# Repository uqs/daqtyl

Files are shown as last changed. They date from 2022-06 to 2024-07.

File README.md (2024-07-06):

# Ftraqtyl Keyboard

The Ftraqtyl is a family member of the Dactyl-Manuform family of keyboards with
added trackball support for finger-operated trackballs.

The genealogy goes roughly like this, with no claim to be accurate:

- [Dactyl](https://github.com/adereth/dactyl-keyboard): Clojure!
- [ManuForm](https://github.com/jeffgran/ManuForm): thumb cluster
- [Dactyl-ManuForm](https://github.com/tshort/dactyl-keyboard): combination
- [Dactyl-Manuform Mini](https://github.com/l4u/dactyl-manuform-mini-keyboard): Mini thumb cluster
- [carbonfet](https://github.com/carbonfet/dactyl-manuform): new cluster
- [crystalhand](https://github.com/crystalhand/dactyl-keyboard): palm rests
- /u/qqurn, /u/drashna, [/u/noahjoseph](https://github.com/noahprince22/tractyl-manuform-keyboard): trackball mad lads.

## Other variants you should check out

- https://github.com/okke-formsma/dactyl-manuform-tight/
- https://github.com/geoffder/dometyl-keyboard

Shoutout also to the folks from OhKeycaps who inadvertently got me started on this journey.

## Notable Changes

- Trackball holder for the fingers (!) of the right hand.
- Trackballs don't use dowels or ball bearings, but press-fit steel balls. I prefer the feel of this, but might try BTUs also.
- Tighter vertical spacing, works for MT3 keycaps.
- Tighter horizontal spacing for first and last column. First column also slanted inwards. Last column splayed a bit.
- Three button cluster based off the "mini" cluster.
- Palm rests without silicone pads.
- Rolling rotary encoders (like a proper mouse wheel).
- Support for 34mm and 44mm trackballs.

## Generate OpenSCAD and STL models

This requires the unreleased (yet) version of scad-clj, you should be able to clone scad-clj and run `lein jar && lein install`.
(This will be obsolete once https://github.com/farrellm/scad-clj/issues/49 has been resolved).

To create everything, just run `lein generate && make -j4 all`, otherwise:

* Run `lein repl`, enter: `(load-file "src/dactyl_keyboard/dactyl.clj")`
* This will regenerate the `things/*.scad` files
* Use OpenSCAD to open a `.scad` file.
* Make changes to design, repeat `load-file`, OpenSCAD will watch for changes and rerender.
* When done, use OpenSCAD to render and export STL files, either from UI or using `openscad --export-format binstl -o right.stl things/right.scad`

## License

Copyright © 2015-2024 Matthew Adereth, Tom Short, Leo Lou, carbonfet, crystalhands, and Ulrich Spörlein.

The source code for generating the models is distributed under the [GNU AFFERO GENERAL PUBLIC LICENSE Version 3](LICENSE).

The generated models are distributed under the [Creative Commons Attribution-ShareAlike 4.0 International (CC BY-SA 4.0)](LICENSE-models).

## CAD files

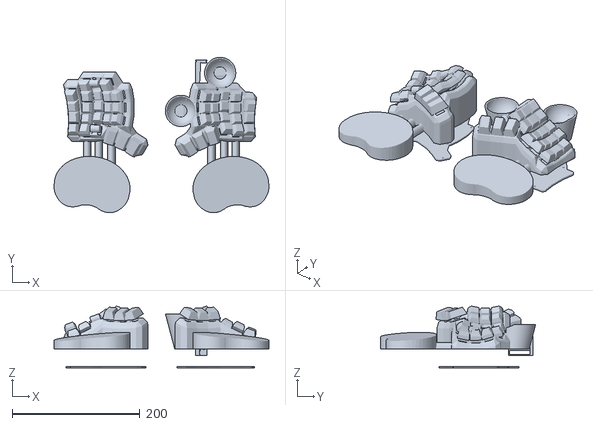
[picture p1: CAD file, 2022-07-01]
things/all-test.dec.stl
337.1 x 243.6 x 97.2

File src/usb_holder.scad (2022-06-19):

/* there's tons of magic numbers here because 
 * i exported a semi-done parametric version from clojure
 * and didn't fix all the formulas for x and y translates....
 * before getting it fully working and for getting how the working scad version
 * diverged from the clojure version.......................
 *
 * sorry future person trying to change this, you will need 
 * a strong dragon spear to modify any 'kinda adjustable' values */

reset_holder = true;
vertical = true;
cutout_blank = false;
show_previous = false;

controller_adj = 0.0;

usb_holder_x = 30.6;       // kinda adjustable
usb_holder_y = 38.8 + controller_adj;       // kinda adjustable
usb_holder_z = reset_holder? 15 : 8.4;        // kinda adjustable

usb_holder_border = 1.5;   // kinda adjustable

/* this combination of controller and usb_c dimensions 
 * friction fits both generations of elite-c controllers */
usb_elite_c_x = 18.7;      // kinda adjustable
usb_elite_c_y = 33.4 + controller_adj;      // mostly adjustable
usb_elite_c_side_cut = 6;  // adjustable

usb_c_x = 9.3;             // adjustable
usb_c_z = 4.0;             // kinda adjustable

trrs_x = 6.2;              // mostly adjustable
trrs_y = 12.7;             // kinda adjustable
trrs_r = 3.25;             // adjustable

usb_holder_center_x = usb_holder_x / 2;
usb_holder_center_y = usb_holder_y / 2;
usb_holder_center_z = usb_holder_z / 2;

usb_holder_notch_xy = usb_holder_border;
usb_holder_notch_down = usb_holder_border * usb_holder_notch_xy;
usb_holder_notch_half = usb_holder_notch_xy / 2;

$fn = 100;

module basicShape() {
  difference () {
    //basic starting shape to cut away from  `
    cube ([usb_holder_x, usb_holder_y, usb_holder_z], center=true);
    
    left_cut_x = 2 * usb_holder_border;
    left_cut_y = 3 * usb_holder_border;
    
    bottom_cut_x = (left_cut_x + trrs_x);
    bottom_cut_y = (left_cut_x + trrs_x);
    
    cut1_x = (usb_holder_center_x -  usb_holder_border);
    cut1_y = (usb_holder_center_y - (usb_holder_center_y - left_cut_y/2));
    
    cut2_x = (usb_holder_center_x - (bottom_cut_x / 2));
    //cut2_y = (usb_holder_center_y - (- usb_holder_center_y (16.6 / 2))); //todo
      
    //misc magic numbers
    if (!cutout_blank) {
      union () {
        translate ([-cut1_x, -cut1_y, 0]) {
          cube ([left_cut_x, (usb_holder_y - left_cut_y), 99], center=true);
        }
        translate ([-cut2_x, -8.3, 0]) {
          cube ([bottom_cut_x, (usb_holder_y - 16.6), 99], center=true);
        }
        rotate (a=3, v=[1, 0, 0]) {
          top_cut_adjust = reset_holder? 1.75*usb_holder_border : usb_holder_border;
          translate ([0, -(usb_holder_border * 3), (usb_holder_z / top_cut_adjust) ]) {
            cube ([usb_holder_x, usb_holder_y, usb_holder_z], center=true);
          }
        }
      }
    }
    
    if (!vertical) {
      // side notches that key into other object
      notch_x = (usb_holder_center_x - usb_holder_notch_half);
      notch_y = (usb_holder_center_y - usb_holder_notch_down);
      translate ([ notch_x, notch_y, 0]) { notch(); }
      translate ([-notch_x, notch_y, 0]) { notch(); }
    }
  }
}
module notch() {
    cube ([usb_holder_notch_xy, usb_holder_notch_xy - 0.05, 30.6], center=true);
}

module trrsCutouts() {
    trrs_floor = 1;
    trrs_squareCutoutHeight = 12;
    trrs_squareCutoutHeightOffset = trrs_floor - usb_holder_center_z + trrs_squareCutoutHeight/2;
    translate ([-9.2, 11.65 + controller_adj/2, trrs_squareCutoutHeightOffset]) {
        cube ([trrs_x, trrs_y, trrs_squareCutoutHeight], center=true);
    }
    
    trrsAngle_z_adjust = reset_holder? 0.5 : 4;
    trrsAngle_z_factor = reset_holder? 0.5 : 1;
    translate ([-9.2, 11.65-trrs_y/3+ controller_adj/2, trrsAngle_z_adjust * usb_holder_border]) {
        rotate (a=-72.0, v=[1, 0, 0]) {
            cube ([trrs_x, trrs_y, usb_holder_z * trrsAngle_z_factor], center=true);
        }
    }
    
    trrs_y_offset = (usb_holder_center_y - (usb_holder_border / 2) +0.01);// + controller_adj;
    trrs_z_offset = (usb_holder_center_z - (trrs_floor + trrs_r));
    translate ([-9.1, trrs_y_offset, -trrs_z_offset]) {
        rotate (a=90.0, v=[1, 0, 0]) {
           cylinder (h=(usb_holder_border * 2), r=trrs_r, center=true);
        }
    }
}

module resetCutout() {
    reset_xz = 7.1;
    reset_y = 4.4;
    reset_floor = usb_holder_z / 1.5 ;
    reset_r = 1.90;
    
    reset_x_offset = usb_holder_center_x - usb_elite_c_x / 2 - usb_holder_border;
    reset_y_offset = usb_holder_center_y - usb_elite_c_y - usb_holder_border;
    reset_z_offset = usb_holder_center_z - (reset_floor + reset_r);
    
    translate ([reset_x_offset, -reset_y_offset, -reset_z_offset]) {
        cube ([reset_xz, reset_y, reset_xz], center=true);
    }
    
    translate ([reset_x_offset, 0, -reset_z_offset]) {
        rotate (a=90.0, v=[1, 0, 0]) {
          cylinder (h=99, r=reset_r, center=true);
        }
    }
}

module eliteC() {
    x_offset = ( (usb_holder_center_x - (usb_elite_c_x / 2)) - usb_holder_border);
    y_offset = (-(usb_holder_center_y - (usb_elite_c_y / 2)) + usb_holder_border);
    z_offset = usb_holder_border;
    translate ([x_offset, y_offset, z_offset]) {
        cube ([usb_elite_c_x, usb_elite_c_y, usb_holder_z], center=true);
    }

    left_cut_x  = ((usb_holder_center_x - (usb_elite_c_x / 2)) - ((usb_elite_c_x / 2) - (usb_elite_c_side_cut / 2)) - usb_holder_border);
    right_cut_x = ((usb_holder_center_x - (usb_elite_c_x / 2)) + ((usb_elite_c_x / 2) - (usb_elite_c_side_cut / 2)) - usb_holder_border);
    translate ([left_cut_x , y_offset, 0]) { circuitBoardSlots(); }
    translate ([right_cut_x, y_offset, 0]) { circuitBoardSlots(); }

    usbPort_z_adjust = reset_holder? -3.6 : -0.3;
    translate([0, 0, usbPort_z_adjust]) {
        usbPortCutout();
        usbRecessCutout();
    }
}

module circuitBoardSlots() {
    cube ([usb_elite_c_side_cut, usb_elite_c_y, 99], center=true);
}

module usbPortCutout() {
    usbPortCenter = ((usb_holder_center_x - (usb_elite_c_x/2)) - usb_holder_border);
    usbPortCenterCut = (usb_c_x - usb_c_z);
    usbPortSideOffset = usbPortCenterCut / 2 + 0.15;
    usbPortCenterCutLength = 20;
    
    translate ([usbPortCenter, 20, 0]) {
      hull() {
	rotate (a=90.0, v=[1, 0, 0]) {
	  translate ([-usbPortSideOffset, 0, 0]) {
	    cylinder (h=usbPortCenterCutLength, r=usb_c_z/2);
	  }
	  translate ([usbPortSideOffset, 0, 0]) {
	    cylinder (h=usbPortCenterCutLength, r=usb_c_z/2);
	  }
	}
      }
    }
}

module usbRecessCutout() {
    usb_c_cover_plate = usb_holder_border;
    recess_y = (usb_holder_y - usb_elite_c_y - usb_holder_border - usb_c_cover_plate);
    recess_z = 8;
    translate ([0, (usb_holder_center_y - (recess_y / 2) +0.01), 0]) {
        
        translate ([0, 0, 0]) {
            rotate (a=90.0, v=[1, 0, 0]) {
                cylinder (h=recess_y, r=3.25, center=true);
            }
        }
        translate ([(+(usb_holder_center_x - (usb_elite_c_x/2)) - usb_holder_border), 0, 0]) {
            cube ([12.5, recess_y, recess_z], center=true);
        }
        translate ([(usb_c_x), 0, 0]) {
            rotate (a=90.0, v=[1, 0, 0]) {
                cylinder (h=recess_y, r=3.25, center=true);
            }
        }
    }
}

// main method
module usb_holder() {
    //adjust origin to front fact, bottom, mostly to match existing STLs
    translate([0, -(usb_holder_y/2), (usb_holder_z/2)]) {
        
        difference () {
            basicShape();
            if (!cutout_blank) {
                trrsCutouts();
                eliteC();
                if (reset_holder) {
                    resetCutout();
                }
            }
        }
    }
    if (show_previous) {
        color( "grey", 0.6 )
          translate([0,0,0])
            union() {
              rotate([0,0,0])
              import("../elite-c_holder_w_reset.stl");
            }
    }
}
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

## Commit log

2020-05-03 Fix keycaps and add plate generation
2020-06-25 Add files via upload
    Slightly tweaked the shape of the TRRS holder & loosened the tolerance on the TRRS hole.
    [controller holder (elite-c).stl, controller holder.stl]
2020-07-27 Update dactyl.clj
    Minor tweak to thumb cluster, tweak screw post to remove domed top (shortening it).
2020-11-12 Update dactyl.clj
    Fixed keycap colliding with case by widening switch plate slightly, other minor tweaks.
2020-11-13 Update dactyl.clj
    Increased thickness of the 'switchplate' to 4.5mm. Increased thickness of the web connectors to 4.5mm as well to smooth out the bottom of the switchplate.
2020-11-16 Update dactyl.clj
    Fixing a gap in the connectors when extra-row was set to false.
2020-12-06 Update dactyl.clj
    Screw posts now behave better when switching between different layout styles.
2021-03-03 Add files via upload
    Updated to shorter holders, elite-c holder should now be compatible with elite-c v4.
    [elite-c holder.STL, pro micro holder.STL]
2021-04-11 Update dactyl.clj
    Minor bugfix for bottom plate generation; should behave better with certain combinations now.
2021-04-25 Update dactyl.clj
    Added a 6th screw post near the middle of the back wall
2021-06-18 Update dactyl.clj
    Added more lines for top-middle screw post definition.
2021-08-28 Let's try this one, first build with a mini cluster
    Use more tenting and fix the screw inset offsets that are
    then off.
    TODO: add the holes for the wrist rest attachment
2021-08-29 Bring over the wrist rest with connectors from crystalhand
2021-09-12 name files a bit better, drop laser plate, add bottom plate to test
2021-09-12 cut off the bottom of the wirst rest cylinders properly
2021-09-20 Make the wrist-rest a bit hollow and thus cheaper to print
2021-09-25 Remove thumb connectors to the extra row (what???) that don't change the output at all.
2021-09-27 Change from MX switch holder to some half-assed structure to hold the rotary encoder
2021-09-27 Fold pinky-connectors and keyhole-inner inline. Duplicate the left model, as we need to parametrize it shortly.
2021-09-27 Provide my own version of the 3 button cluster, which is simply the mini cluster with 2 keys removed.
    Need to check clearing for 1.5u keys still.
2021-10-09 Make the bottom plate a recessed plate and move the screw inserts up.
    This conflicts with a lot of things and the whole case needs to be
    elevated a bit.
    I'm not happy with the uneven width of the walls anyway ...
2021-10-31 Place new, custom trackball holder for a test print.
2021-10-31 Fix the missing screw recess for the bottom plate.
    It still is not right and won't fit into the top ...
2021-10-31 Fix thumb cluster oddity and remove the need to cut off the bottom
    Increase height a little so we have space for the plate and screw
    inserts. This will need to be scaled down a little again.
2021-10-31 Order screw posts
2021-11-01 Try with the encoder place in the last row as well.
2021-11-01 Move screw inserts around some more and fix them in the OpenSCAD preview.
2021-11-02 Add the encoder cylinder to the preview and fix trackball z translation.
    Turn on all STL exports for publishing v1 as well.
2021-11-03 Shear the trackball holder a bit towards the case.
2021-11-04 Fix some more thumb cluster nits and the palm rest connectors and cutouts
2021-11-11 Fix screw insets to be more like crystalhand's
2021-11-11 Fix two holes in the model, sheesh.
2021-11-13 Lower keeb by 6mm, enlarge the screw-inserts and shrink the bottom plate a little.
2021-11-13 Add sensor holder and cutout
    This is no good though, sliding the sensor in from the top obviously
    won't work. Sigh ...
2021-11-21 Encoder only on the left side, on the right it inteferes with my numpad layer.
2021-11-21 Switch to 4x5! Hurray for combos!
2021-11-22 Slim down the encoder plate, but also raise it higher.
2021-11-27 Tweaks to the encoder plate to improve fit and access to pins.
2021-11-28 Tweak the connectors around the encoder plate to allow easier access from the bottom for soldering them.
2021-11-29 Convert more stuff to STL for inspection in FreeCAD
2021-11-29 Fix the projection for the bottom plate by pluggin encoder holes.
2021-11-29 Break down walls between keyboard and trackball, noting that the sensors will not fit with the current design.
    Also make all models compile again.
2021-11-30 Remove STLs w/o sources
    [elite-c holder.STL, pro micro holder.STL, shim.stl]
2021-11-30 Rename source and add the preview STL for the GitHub viewer
    [all-test.dec.stl]
2021-12-12 Mirror the encoder plate once more, so it comes out correct on the left side.
2021-12-12 Fix two holes in the model, due to walls that are just a tad too thin.
2022-01-15 Use threads to parallize all the model generation.
    Update the project file with some proper URLs as well.
2022-01-15 Tweak some dimensions here and there for better fit of encoder and sensor (hopefully)
2022-01-16 More encoder and sensor tweaks
2022-01-17 Make the encoder fit snugly and slight thumb tweak
2022-01-17 Fit the encoder plate into the keywell again.
2022-01-19 Move encoders up about another 4mm or so
2022-01-19 Make the wrist rest cheaper and faster to print, which is quite non intuitive, but it's what Prusa Slicer tells me.
2022-02-06 Due to tolerances, make the bottom plates a bit thinner, so they will sit flush with the case walls.
2022-02-20 Trackball holder with sensor at the bottom and maybe support-less printable
2022-03-27 Fix the wrist rest attachments a bit better
2022-04-09 Add a column rotation and a twist factor.
    This is used to tilt the inner column more to the index finger, and to
    rotate the pinky column more aggressively towards the hand.
2022-04-09 Thumb tweaks including palm rest connectors.
2022-04-10 Fix a manifold issue on the thumb connector hulls
2022-04-10 Tweak the web post connectors for the encoder plate
2022-04-30 Put a dent in the dimples and allow the sensor to slide in from the bottom at an angle
2022-04-30 Have the sensor supports move along with changes in radius
    Will be used for testing a ca. 50mm ball
2022-04-30 Snapshot work on fitting the holders to the case properly
2022-04-30 Parametrize the offset to work with 34mm and 50mm balls
2022-05-09 Fix the encoder caps placement and tweak a little
2022-05-09 44mm test print
    Plug a hole in the holder to save on printing time (infill is faster
    than walls!)
2022-05-09 Fix the bottom plate and cutouts ... again.
2022-05-09 Update decimated STL for preview
    [all-test.dec.stl]
2022-05-11 Remove the unused oval cutout for the sensor board and embiggen the real one.
    Also support the board better and gives it more room to move.
2022-05-14 Further tweaks to improve sensor to ball position
2022-05-15 Tweak the trackball attachments and the inner column and thumb after a test print with MT3 caps
2022-05-30 Tweak with more clearance to fit the sensor board
2022-06-05 Bring in dereknheiley's USB holder for elite-C, needs some tweaks though.
    [usb_holder.scad]
2022-06-09 Adjust the MCU holder to fit an Elite-C snugly
    [usb_holder.scad]
2022-06-10 Tweak the distance of sensor to ball after several test prints
    also slant the cylinder again for a smaller footprin
2022-06-10 Add cutouts for cables and the MCU holder
2022-06-10 Fix up all the screw thingies for the bottom plates.
2022-06-11 Turn these on for the final print
2022-06-12 Fix MT3 keycap collision around the encoder walls
2022-06-18 Adjust tolerances for the MCU holder
    [usb_holder.scad]
2022-06-19 even more tolerances
    [usb_holder.scad]
2022-07-01 Raise the hole for the cable to not collide with the bottom plate.
2022-07-01 Upload final (?) decimated preview
    [all-test.dec.stl]
2022-07-01 Tweak the retention tab, as my key switches don't fit correctly.
2024-07-15 Much better way of cutting the sensor cutout through the back wall.
